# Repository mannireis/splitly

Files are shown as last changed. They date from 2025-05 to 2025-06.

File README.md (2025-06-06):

# splitly

Splitly is a 60key wireless split keyboard that was made with support of https://hackclub.com/!

The Schematic:



The PCB:





The Case:



image(1)

Bom:

| Item | Price | Source |
|---|---|---|
| PCB | $23.07  | [JLCPCB](https://jlcpcb.com) |
| Diodes | $1.00 | [AliExpress](https://tinyurl.com/diodesali) |
| XIAO nRF52840 | $36.83  | [The Pi Hut](https://thepihut.com/) |
| Kailh Choc Low Profile Switches| $40.69  | [42Keebs](https://42keebs.eu/shop/switches/choc/kailh-choc-low-profile-switches/?attribute_type=Pink) |
| Batteries | $8.16 | [AliExpress](https://tinyurl.com/baterryali) |
| ELEGOO PLA Filament 1.75 1kg | $18.28  | [Short URL](https://shorturl.at/NSEPR) |
| **Total (approx.)** | **$150**| *(includes shipping and misc. costs)* |

In total this took me about 19 hours.

The hardest part about this was making the case and reasearh of all the parts.

My inspiration was mostly the bayleaf keyboard:

https://www.graz.io/articles/bayleaf-wireless-keyboard

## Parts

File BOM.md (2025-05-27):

- PCB $23.07 jlcpcb
- Diodes $1 https://tinyurl.com/diodesali
- XIAO nRF52840 $36.83 https://thepihut.com/
- Switches $40.69 https://42keebs.eu/shop/switches/choc/kailh-choc-low-profile-switches/?attribute_type=Pink
- Batterys $8.16 https://tinyurl.com/baterryali
- ELEGOO PLA Filament 1.75 1kg White, 3D $18.28 https://shorturl.at/NSEPR

  Total $128.03

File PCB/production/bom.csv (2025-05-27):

Designator | Footprint | Quantity | Value | LCSC Part #
D1, D10, D11, D12, D13, D14, D15, D16, D17, D18, D19, D2, D20, D21, D22, D23, D24, D25, D26, D27, D28, D29, D3, D30, D31, D32, D33, D34, D35, D36, D37, D38, D39, D4, D40, D41, D42, D43, D44, D45, D46, D47, D48, D49, D5, D50, D51, D52, D53, D54, D55, D56, D57, D58, D59, D6, D60, D7, D8, D9 | D_SOD-123 | 60 | D
SW1, SW10, SW11, SW12, SW13, SW14, SW15, SW16, SW17, SW18, SW19, SW2, SW20, SW21, SW22, SW23, SW24, SW25, SW26, SW27, SW28, SW29, SW3, SW30, SW31, SW32, SW33, SW34, SW35, SW36, SW37, SW38, SW39, SW4, SW40, SW41, SW42, SW43, SW44, SW45, SW46, SW47, SW48, SW49, SW5, SW50, SW51, SW52, SW53, SW54, SW55, SW56, SW57, SW58, SW59, SW6, SW60, SW7, SW8, SW9 | Hotswap_Choc_V1_1.00u | 60 | SW_Push_45deg
U1, U2 | XIAO-nRF52840-DIP | 2 | XIAO-nRF52840-DIP

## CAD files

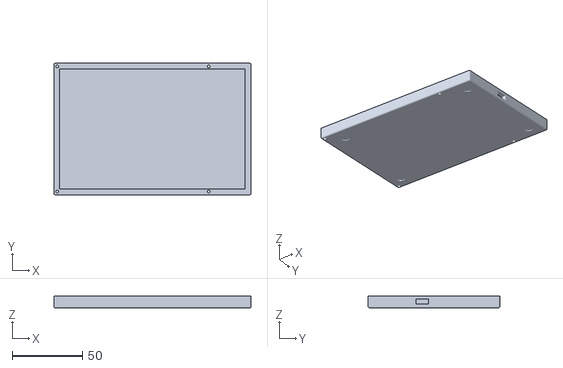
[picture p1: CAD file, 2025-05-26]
3D Models/Bottom Left.stl
140.0 x 93.6 x 8.50

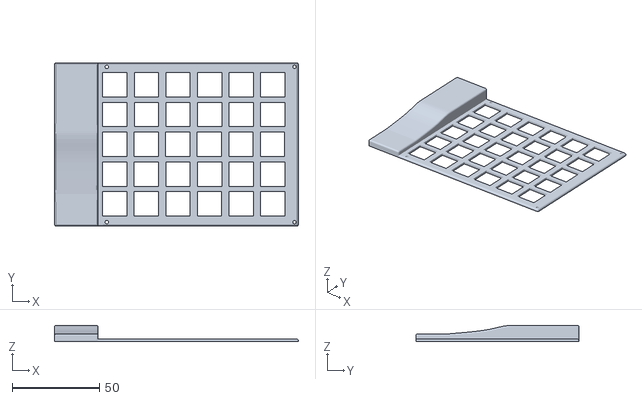
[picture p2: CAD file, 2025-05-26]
3D Models/Top Right.stl
140.0 x 93.6 x 9.30

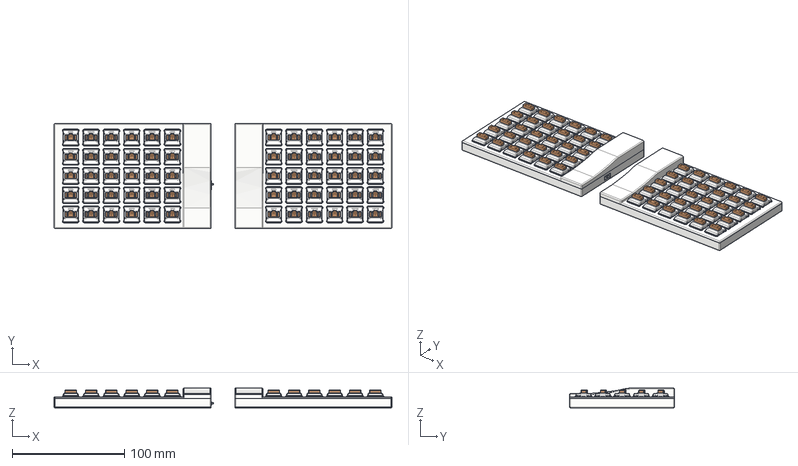
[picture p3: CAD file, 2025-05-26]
3D Models/splitly.step
300.9 x 93.6 x 17.8 mm
Choc_V1 x 60
BOSS-EXTRUDE14_8_ x 2
BOSS-EXTRUDE7_4_ x 2
BOSS-EXTRUDE7_3_ x 2
BOSS-EXTRUDE14_4_ x 2
BOSS-EXTRUDE14_2_ x 2
BOSS-EXTRUDE14_11_ x 2
BOSS-EXTRUDE7_7_ x 2
BOSS-EXTRUDE14_9_ x 2
BOSS-EXTRUDE14_3_ x 2
BOSS-EXTRUDE14_7_ x 2
MIRROR2 x 2
BOSS-EXTRUDE14_5_ x 2
BOSS-EXTRUDE14_12_ x 2
BOSS-EXTRUDE7_8_ x 2
BOSS-EXTRUDE7_1_ x 2
BOSS-EXTRUDE14_10_ x 2
BOSS-EXTRUDE7_9_ x 2
BOSS-EXTRUDE14_6_ x 2
BOSS-EXTRUDE14_1_ x 2
BOSS-EXTRUDE7_6_ x 2
BOSS-EXTRUDE7_2_ x 2
CUT-EXTRUDE5 x 2
BOSS-EXTRUDE7_5_ x 2
Shield x 2
Pins x 2
CAP x 4
ANT1 x 2
Silkscreen x 2
CAP 3 x 2
LED x 2
USR x 2
splitly_PCB_1
splitly_PCB_2
JS202011CQN

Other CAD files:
3D Models/Bottom Right.stl
3D Models/Top Left.stl

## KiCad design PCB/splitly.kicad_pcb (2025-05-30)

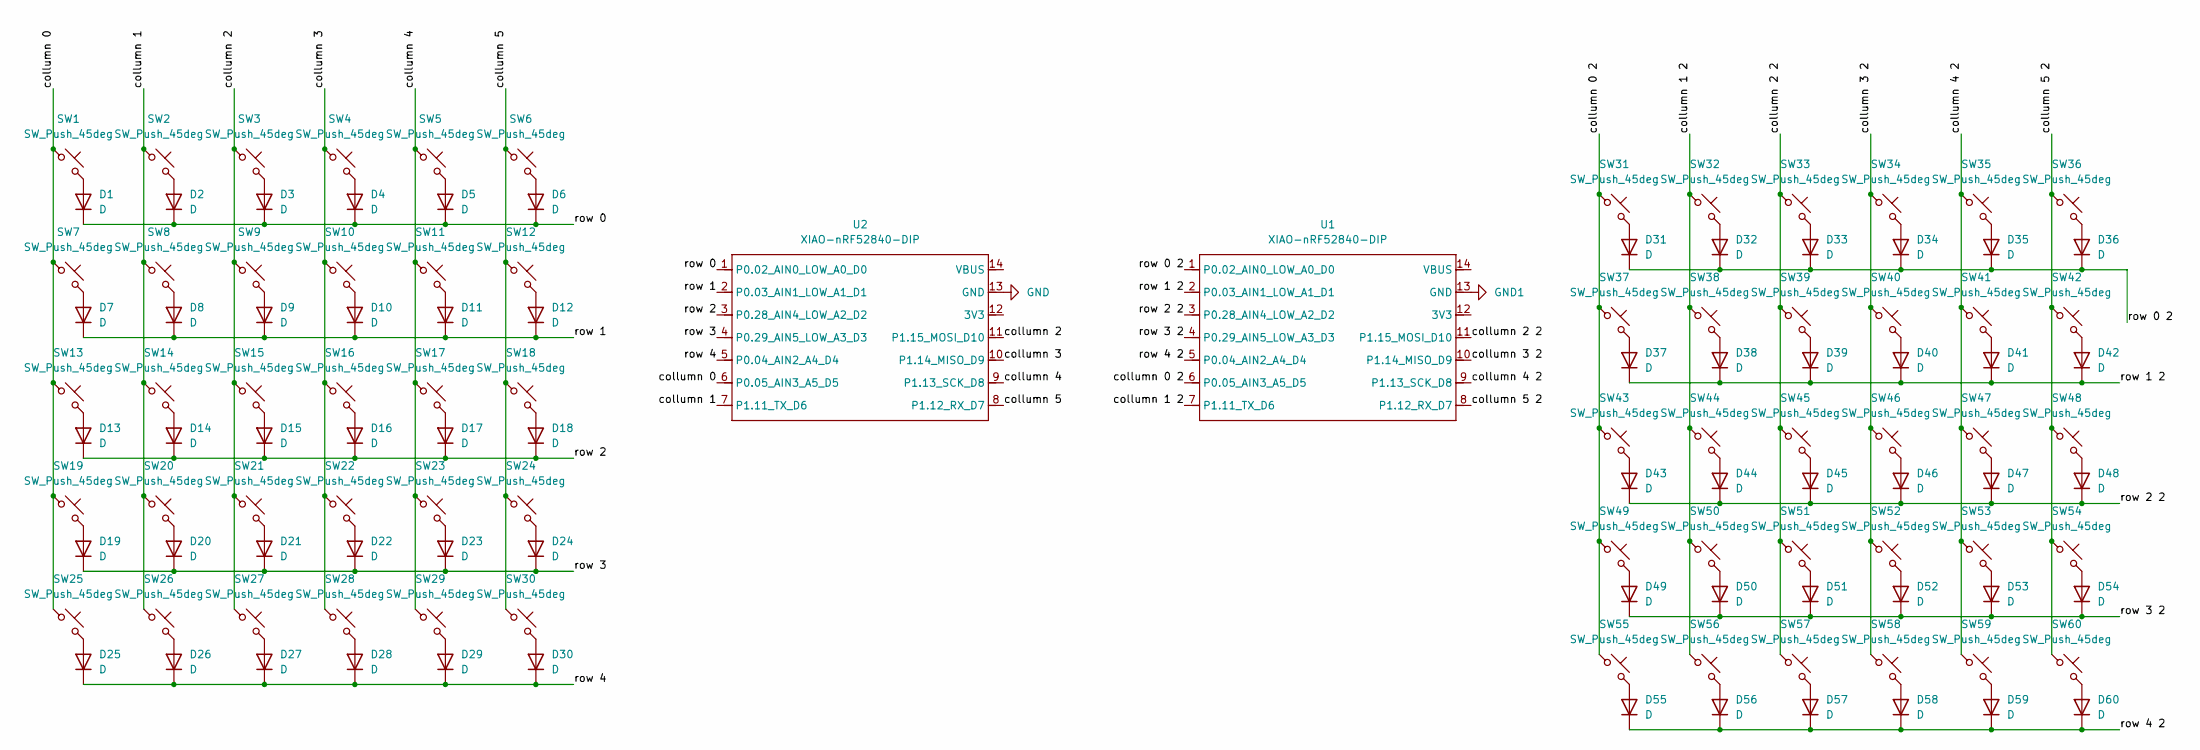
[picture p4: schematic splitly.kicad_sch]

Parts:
D1, D2, D3, D4, D5, D6, D7, D8, D9, D10, D11, D12, D13, D14, D15, D16, D17, D18, D19, D20, D21, D22, D23, D24, D25, D26, D27, D28, D29, D30, D31, D32, D33, D34, D35, D36, D37, D38, D39, D40, D41, D42, D43, D44, D45, D46, D47, D48, D49, D50, D51, D52, D53, D54, D55, D56, D57, D58, D59, D60: D; Diode_SOD-123
SW1, SW2, SW3, SW4, SW5, SW6, SW7, SW8, SW9, SW10, SW11, SW12, SW13, SW14, SW15, SW16, SW17, SW18, SW19, SW20, SW21, SW22, SW23, SW24, SW25, SW26, SW27, SW28, SW29, SW30, SW31, SW32, SW33, SW34, SW35, SW36, SW37, SW38, SW39, SW40, SW41, SW42, SW43, SW44, SW45, SW46, SW47, SW48, SW49, SW50, SW51, SW52, SW53, SW54, SW55, SW56, SW57, SW58, SW59, SW60: SW_Push_45deg; Hotswap_Choc_V1_1.00u
U1, U2: XIAO-nRF52840-DIP

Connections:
/collumn 0: SW1.1, SW7.1, SW13.1, SW19.1, SW25.1, U2.6 (P0.05_AIN3_A5_D5)
/collumn 0 2: SW31.1, SW37.1, SW43.1, SW49.1, SW55.1, U1.6 (P0.05_AIN3_A5_D5)
/collumn 1: SW2.1, SW8.1, SW14.1, SW20.1, SW26.1, U2.7 (P1.11_TX_D6)
/collumn 1 2: SW32.1, SW38.1, SW44.1, SW50.1, SW56.1, U1.7 (P1.11_TX_D6)
/collumn 2: SW3.1, SW9.1, SW15.1, SW21.1, SW27.1, U2.11 (P1.15_MOSI_D10)
/collumn 2 2: SW33.1, SW39.1, SW45.1, SW51.1, SW57.1, U1.11 (P1.15_MOSI_D10)
/collumn 3: SW4.1, SW10.1, SW16.1, SW22.1, SW28.1, U2.10 (P1.14_MISO_D9)
/collumn 3 2: SW34.1, SW40.1, SW46.1, SW52.1, SW58.1, U1.10 (P1.14_MISO_D9)
/collumn 4: SW5.1, SW11.1, SW17.1, SW23.1, SW29.1, U2.9 (P1.13_SCK_D8)
/collumn 4 2: SW35.1, SW41.1, SW47.1, SW53.1, SW59.1, U1.9 (P1.13_SCK_D8)
/collumn 5: SW6.1, SW12.1, SW18.1, SW24.1, SW30.1, U2.8 (P1.12_RX_D7)
/collumn 5 2: SW36.1, SW42.1, SW48.1, SW54.1, SW60.1, U1.8 (P1.12_RX_D7)
/row 0: D1.1 (K), D2.1 (K), D3.1 (K), D4.1 (K), D5.1 (K), D6.1 (K), U2.1 (P0.02_AIN0_LOW_A0_D0)
/row 0 2: D31.1 (K), D32.1 (K), D33.1 (K), D34.1 (K), D35.1 (K), D36.1 (K), U1.1 (P0.02_AIN0_LOW_A0_D0)
/row 1: D7.1 (K), D8.1 (K), D9.1 (K), D10.1 (K), D11.1 (K), D12.1 (K), U2.2 (P0.03_AIN1_LOW_A1_D1)
/row 1 2: D37.1 (K), D38.1 (K), D39.1 (K), D40.1 (K), D41.1 (K), D42.1 (K), U1.2 (P0.03_AIN1_LOW_A1_D1)
/row 2: D13.1 (K), D14.1 (K), D15.1 (K), D16.1 (K), D17.1 (K), D18.1 (K), U2.3 (P0.28_AIN4_LOW_A2_D2)
/row 2 2: D43.1 (K), D44.1 (K), D45.1 (K), D46.1 (K), D47.1 (K), D48.1 (K), U1.3 (P0.28_AIN4_LOW_A2_D2)
/row 3: D19.1 (K), D20.1 (K), D21.1 (K), D22.1 (K), D23.1 (K), D24.1 (K), U2.4 (P0.29_AIN5_LOW_A3_D3)
/row 3 2: D49.1 (K), D50.1 (K), D51.1 (K), D52.1 (K), D53.1 (K), D54.1 (K), U1.4 (P0.29_AIN5_LOW_A3_D3)
/row 4: D25.1 (K), D26.1 (K), D27.1 (K), D28.1 (K), D29.1 (K), D30.1 (K), U2.5 (P0.04_AIN2_A4_D4)
/row 4 2: D55.1 (K), D56.1 (K), D57.1 (K), D58.1 (K), D59.1 (K), D60.1 (K), U1.5 (P0.04_AIN2_A4_D4)
GND: U2.13 (GND)
GND1: U1.13 (GND)
unnamed: D1.2 (A), SW1.2
unnamed: D2.2 (A), SW2.2
unnamed: D3.2 (A), SW3.2
unnamed: D4.2 (A), SW4.2
unnamed: D5.2 (A), SW5.2
unnamed: D6.2 (A), SW6.2
unnamed: D7.2 (A), SW7.2
unnamed: D8.2 (A), SW8.2
unnamed: D9.2 (A), SW9.2
unnamed: D10.2 (A), SW10.2
unnamed: D11.2 (A), SW11.2
unnamed: D12.2 (A), SW12.2
unnamed: D13.2 (A), SW13.2
unnamed: D14.2 (A), SW14.2
unnamed: D15.2 (A), SW15.2
unnamed: D16.2 (A), SW16.2
unnamed: D17.2 (A), SW17.2
unnamed: D18.2 (A), SW18.2
unnamed: D19.2 (A), SW19.2
unnamed: D20.2 (A), SW20.2
unnamed: D21.2 (A), SW21.2
unnamed: D22.2 (A), SW22.2
unnamed: D23.2 (A), SW23.2
unnamed: D24.2 (A), SW24.2
unnamed: D25.2 (A), SW25.2
unnamed: D26.2 (A), SW26.2
unnamed: D27.2 (A), SW27.2
unnamed: D28.2 (A), SW28.2
unnamed: D29.2 (A), SW29.2
unnamed: D30.2 (A), SW30.2
unnamed: D31.2 (A), SW31.2
unnamed: D32.2 (A), SW32.2
unnamed: D33.2 (A), SW33.2
unnamed: D34.2 (A), SW34.2
unnamed: D35.2 (A), SW35.2
unnamed: D36.2 (A), SW36.2
unnamed: D37.2 (A), SW37.2
unnamed: D38.2 (A), SW38.2
unnamed: D39.2 (A), SW39.2
unnamed: D40.2 (A), SW40.2
unnamed: D41.2 (A), SW41.2
unnamed: D42.2 (A), SW42.2
unnamed: D43.2 (A), SW43.2
unnamed: D44.2 (A), SW44.2
unnamed: D45.2 (A), SW45.2
unnamed: D46.2 (A), SW46.2
unnamed: D47.2 (A), SW47.2
unnamed: D48.2 (A), SW48.2
unnamed: D49.2 (A), SW49.2
unnamed: D50.2 (A), SW50.2
unnamed: D51.2 (A), SW51.2
unnamed: D52.2 (A), SW52.2
unnamed: D53.2 (A), SW53.2
unnamed: D54.2 (A), SW54.2
unnamed: D55.2 (A), SW55.2
unnamed: D56.2 (A), SW56.2
unnamed: D57.2 (A), SW57.2
unnamed: D58.2 (A), SW58.2
unnamed: D59.2 (A), SW59.2
unnamed: D60.2 (A), SW60.2

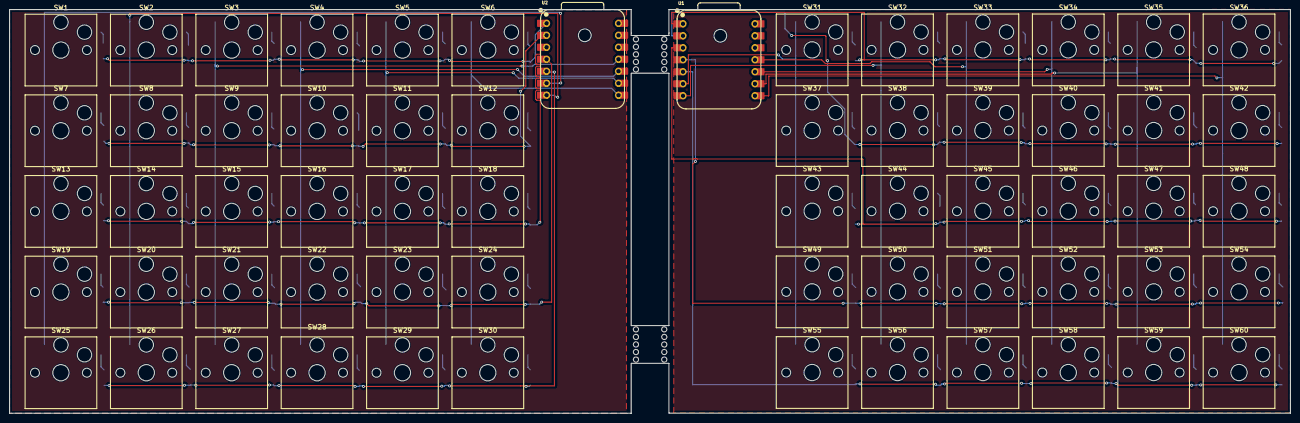
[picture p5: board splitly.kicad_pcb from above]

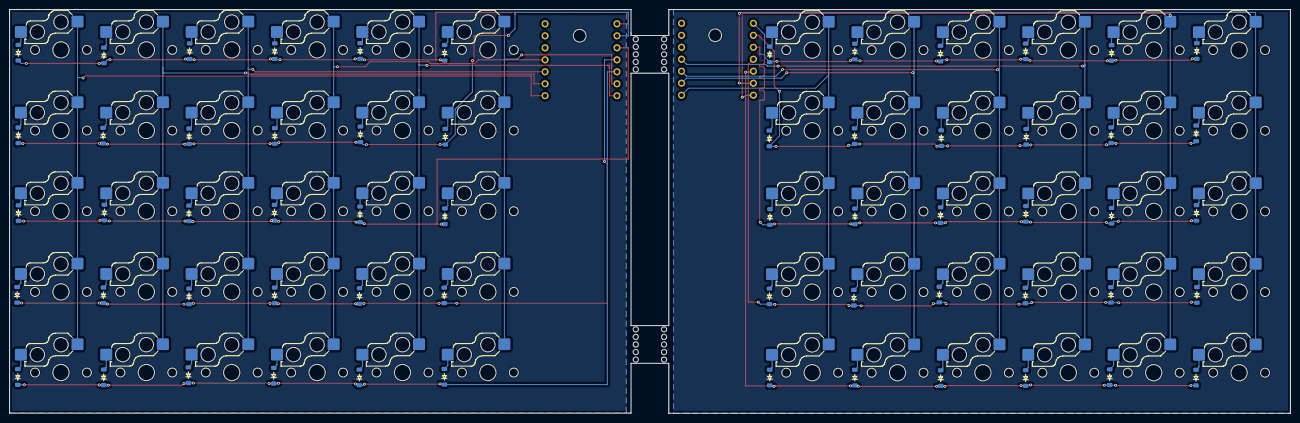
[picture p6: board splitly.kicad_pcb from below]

Board: 2 copper layers, 271.5 x 85.6 mm, 122 parts (60 on the bottom side), 82 nets.

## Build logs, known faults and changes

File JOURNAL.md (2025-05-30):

---
title: "Splitly"
author: "manni"
description: "A low profile wireless split keyboard"
created_at: "2025-06-18"
---

Total Time: 18.5

May 18 - 3 hour session

Did my schematic:


And started making the pcb:


I had a few strugles because i was so dumb so i took a while to make the schematic and i redid the pcb because i needed to flip the switches

May 18 - 4 hour session in huddle w/ @acon!

Made the pcb wired and every thing now i need to make the case!



also drew silk screen :3



May 19 - 1:30 hour session

I was researching about prices and decided on a bunch of different parts!

May 20 - 2:30 hour session

Since i yestarday decided to change to a xiao NRF52840 i made a schematic and the pcb!





May 21 - 3 hour session

I started making the case but scraped everything im fine with not counting this time!

May 22 - 4 hour session

Did the case it took so looooong it was worth it!



May 26 - 0:30 hour session!

Did the other side of the case

May 27 - 3 hour sessions

Doing ZMK

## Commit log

2025-05-18 Add pcb
    [splitly.kicad_pcb, splitly.kicad_sch]
2025-05-18 Made pcb + journal update :3
    [bom.csv, designators.csv, positions.csv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]
2025-05-20 OOOOoooOOO Update
    [bom.csv, designators.csv, positions.csv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]
2025-05-26 Add 3D models
    [Bottom Left.stl, Bottom Right.stl, Top Right.stl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]
2025-05-27 Clean Everything and add stuff to readme
    [Bottom Left.stl, Bottom Right.stl, Top Left.stl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]
2025-05-27 Add a hole to the pcb
    [splitly.kicad_pcb]
2025-05-30 Add things to pcb
    [designators.csv, splitly.kicad_pcb, splitly.kicad_sch]
